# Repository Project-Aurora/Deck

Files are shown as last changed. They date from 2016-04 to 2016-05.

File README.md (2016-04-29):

# Deck
Breakout Boards for 64-Pin ARM MCUs, Keyswitches and IS31FL3732

# Components
+	MCU: The Microcontroller including one IS31FL3732 and a hot-pluggable Power-Connector (either Barrel Jack or MicroUSB)
+	Chain-Connector: Adds the Possibility to Connect two Devices over UART, an additional Master Pin enables automatic Crossover.
+	CherryMX-RGB: Breakout-Board for a single MX-Type Switch with either SMD or THT Backlighting. A Diode on the Back allows for "Ghostless" Operation. A 1-Wire EEPROM could enable Autodetection of different Switches/LEDs as well as Analog Input Devices.
+	LED-Driver: Breakout-Board for one IS31FL3732. These Boards are Chainable, the Device-Address can be freely assigned using external Connections. The Number of Boards can be enumerated using A/D-Conversion on chained Resistors.

Further Description in the Directories.

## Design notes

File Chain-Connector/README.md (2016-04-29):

Chain-Connector: Adds the Possibility to Connect two Devices over UART, an additional Master Pin enables automatic Crossover.

U1 Passes the [1-4]B Input to [1-4]Y when A/B is pulled high, otherwise it [1-4]A is passed through.
The Master Pin serves as A/B and is pulled high when the MCU has succsessfully established Connectivity to a USB-Host.
The "A" state of the Switch means IO1 serves as RX0 and IO2 as TX0.
The "B" state of the Switch means IO1 serves as TX0 and IO2 as RX0.
Because of this the UART-Connection can only be established when one of the two Devices has a USB-Connection, meaning the "RX" of Device1 is connected to Device2's "TX" and vice-versa.
D1 and D2 are needed because connecting the non "TX0" state of 1A and 4B to Ground would pull RX0 low. The EEPROM-Logic doesn't allow for undefined States, thus requireing some kind of connection.
A "Master-LED" (D3) lights up when the Master-Pin is pulled high.

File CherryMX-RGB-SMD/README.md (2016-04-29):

CherryMX-RGB-SMD: Breakout-Board for a single MX-Type Switch with SMD Backlighting. A Diode on the Back allows for "Ghostless" Operation. A 1-Wire EEPROM could enable Autodetection of different Switches/LEDs as well as Analog Input Devices.

The EEPROM is powered by the Row(3.3V) and Column(GND), because of this the Boards location in the Matrix can be determined despite the EEPROMs Address being fixed.

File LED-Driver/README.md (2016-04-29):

LED-Driver: Breakout-Board for one IS31FL3732. These Boards are Chainable, the Device-Address can be freely assigned using external Connections. The Number of Boards can be enumerated using A/D-Conversion on chained Resistors.

P3 offers the Pins necessary to set the Address-Pins on P4.
A table in the bottom right Corner shows an Overview of the Slave-ID(Columns) as well as the required Connections too ADDR1/s(Rows).

JP1 should be bridged on the last Device in Chain, shorting Feedback-IN to 3.3V.
R1 decreases the resulting current on each Device, allowing an AD-Converter Pin on the MCU to "guesstimate" the number of Resistors in Series and thus the Number of Slaves.

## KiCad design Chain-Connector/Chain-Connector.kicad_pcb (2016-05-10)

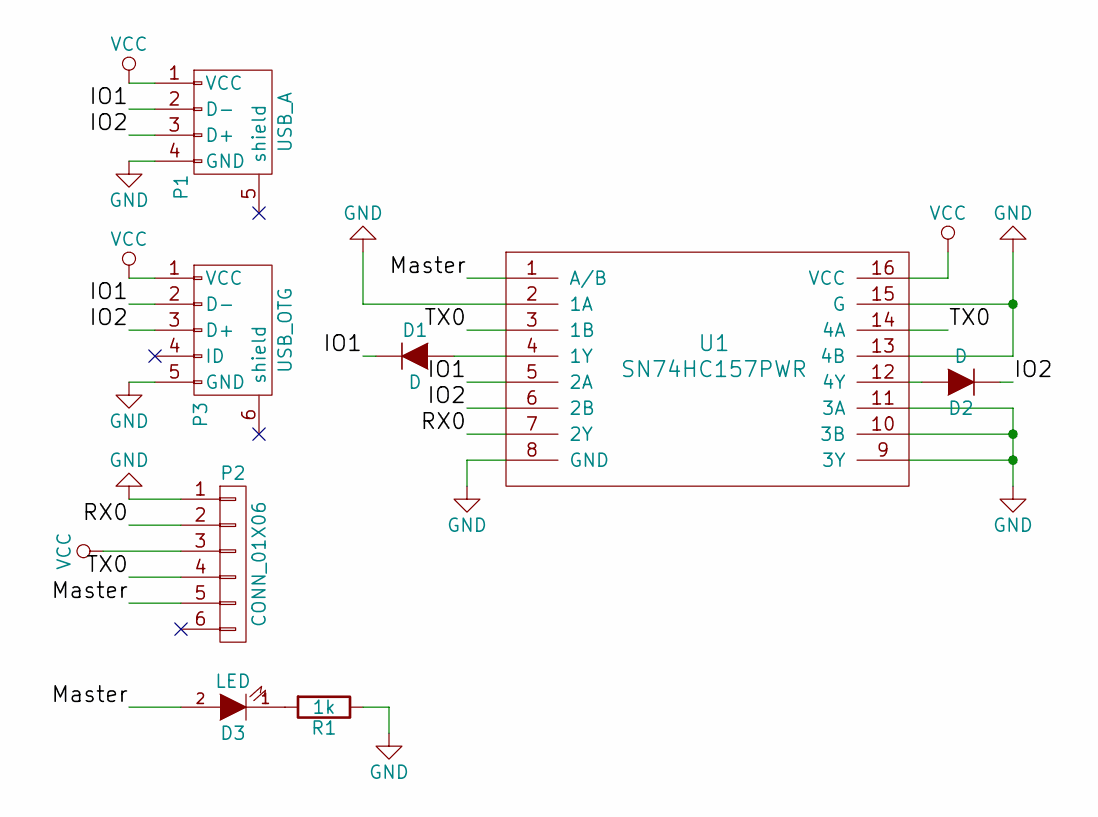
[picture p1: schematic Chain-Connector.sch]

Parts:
D1, D2: D; SOD-123
D3: LED; LED_0805
P1: USB_A
P2: CONN_01X06; Pin_Header_Straight_2x03
P3: USB_OTG; USB_Micro-B
R1: 1k; R_0603
U1: SN74HC157PWR; TSSOP-16_4.4x5mm_Pitch0.65mm

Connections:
/IO1: D1.1 (K), P1.2 (D-), P3.2 (D-), U1.5 (2A)
/IO2: D2.1 (K), P1.3 (D+), P3.3 (D+), U1.6 (2B)
/Master: D3.2 (A), P2.5, U1.1 (A/B)
/RX0: P2.2, U1.7 (2Y)
/TX0: P2.4, U1.3 (1B), U1.14 (4A)
GND: P1.4 (GND), P2.1, P3.5 (GND), R1.1, U1.2 (1A), U1.8 (GND), U1.9 (3Y), U1.10 (3B), U1.11 (3A), U1.13 (4B), U1.15 (G)
unnamed: D1.2 (A), U1.4 (1Y)
unnamed: D2.2 (A), U1.12 (4Y)
unnamed: D3.1 (K), R1.2
VCC: P1.1 (VCC), P2.3, P3.1 (VCC), U1.16 (VCC)

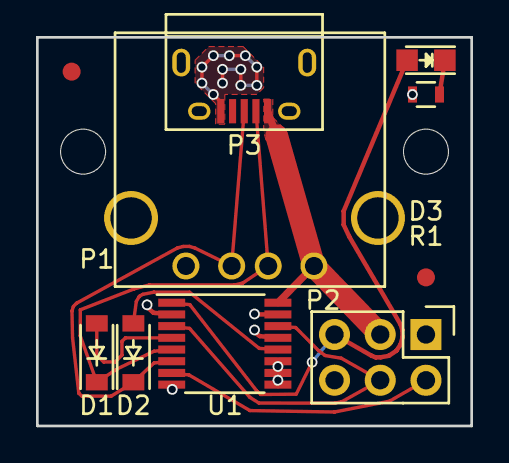
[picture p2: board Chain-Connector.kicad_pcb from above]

Board: 2 copper layers, 24.1 x 21.6 mm, 8 parts (0 on the bottom side), 10 nets.

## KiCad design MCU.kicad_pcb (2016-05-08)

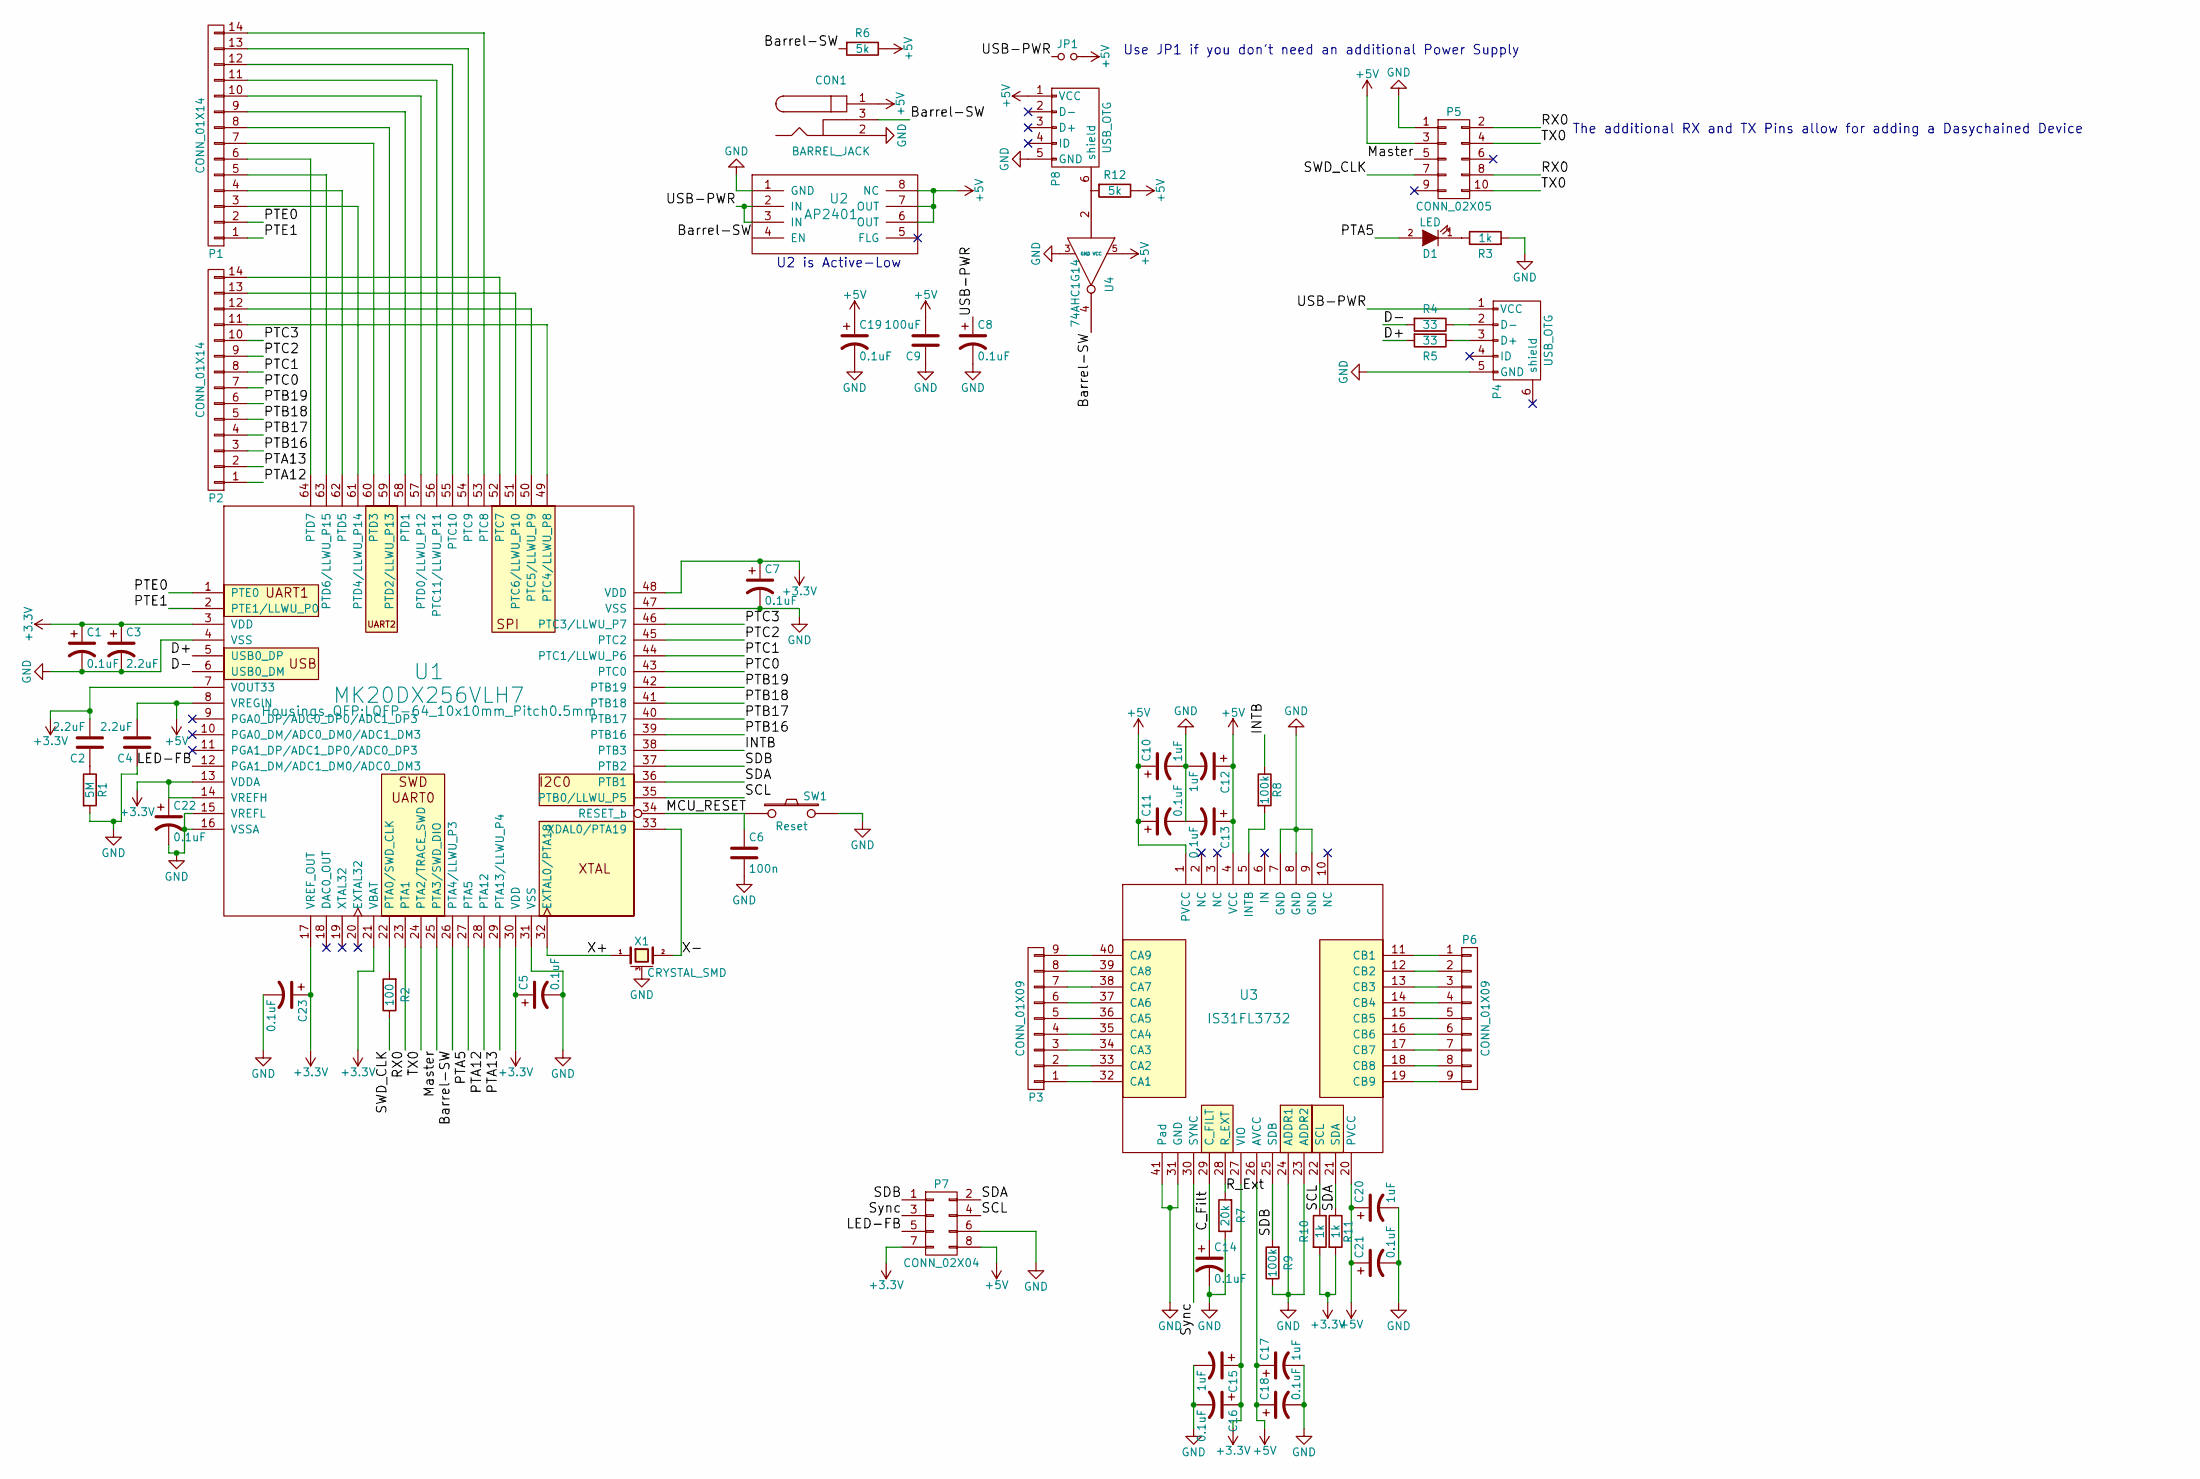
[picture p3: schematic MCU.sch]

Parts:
C1, C5, C7, C8, C11, C13, C14, C16, C18, C19, C21, C22, C23: 0.1uF; C_0603
C2, C3, C4: 2.2uF; C_0603
C6: 100n; C_0603
C9: 100uF; C_0805
C10, C12, C15, C17, C20: 1uF; C_0603
CON1: BARREL_JACK
D1: LED; LED_0805
JP1: Jumper_NO_Small; C_0805
P1, P2: CONN_01X14; Pin_Header_Straight_2x07
P3, P6: CONN_01X09; Pin_Header_Straight_1x09
P4, P8: USB_OTG; USB_Micro-B
P5: CONN_02X05; Pin_Header_Straight_2x05
P7: CONN_02X04; Pin_Header_Straight_2x04
R1: 5M; R_0805
R2: 100; R_0603
R3, R10, R11: 1k; R_0603
R4, R5: 33; R_0603
R6, R12: 5k; R_0603
R7: 20k; R_0603
R8, R9: 100k; R_0603
SW1: Reset; SW_Tactile_SPST_Angled
U1: MK20DX256VLH7; LQFP-64_10x10mm_Pitch0.5mm
U2: AP2401; SO-8
U3: IS31FL3732; UQFN-40-1EP_5x5mm_Pitch0.4mm
U4: 74AHC1G14; SOT-353
X1: CRYSTAL_SMD; crystal_FA238-TSX3225

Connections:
+3V3: C1.1, C2.2, C3.1, C5.1, C7.1, C15.1, C16.1, C22.1, C23.1, P7.7, R10.2, R11.2, U1.3 (VDD), U1.7 (VOUT33), U1.13 (VDDA), U1.14 (VREFH), U1.17 (VREF_OUT), U1.21 (VBAT), U1.30 (VDD), U1.48 (VDD), U3.27 (VIO)
+5V: C4.2, C9.2, C10.1, C11.1, C12.1, C13.1, C17.1, C18.1, C19.1, C20.1, C21.1, CON1.1, JP1.2, P5.3, P7.8, P8.1 (VCC), R6.1, R12.1, U1.8 (VREGIN), U2.6 (OUT), U2.7 (OUT), U2.8 (NC), U3.1 (PVCC), U3.4 (VCC), U3.20 (PVCC), U3.26 (AVCC), U4.5 (VCC)
/Barrel-SW: CON1.3, R6.2, U1.26 (PTA4/LLWU_P3), U2.4 (EN), U4.4
/C_Filt: C14.1, U3.29 (C_FILT)
/D+: R5.2, U1.5 (USB0_DP)
/D-: R4.2, U1.6 (USB0_DM)
/INTB: R8.1, U1.38 (PTB3)
/LED-FB: P7.5, U1.12 (PGA1_DM/ADC1_DM0/ADC0_DM3)
/MCU_RESET: C6.1, SW1.1, U1.34 (RESET_b)
/Master: P5.5, U1.25 (PTA3/SWD_DIO)
/PTA5: D1.2 (A), U1.27 (PTA5)
/PTA12: P2.1, U1.28 (PTA12)
/PTA13: P2.2, U1.29 (PTA13/LLWU_P4)
/PTB16: P2.3, U1.39 (PTB16)
/PTB17: P2.4, U1.40 (PTB17)
/PTB18: P2.5, U1.41 (PTB18)
/PTB19: P2.6, U1.42 (PTB19)
/PTC0: P2.7, U1.43 (PTC0)
/PTC1: P2.8, U1.44 (PTC1/LLWU_P6)
/PTC2: P2.9, U1.45 (PTC2)
/PTC3: P2.10, U1.46 (PTC3/LLWU_P7)
/PTE0: P1.2, U1.1 (PTE0)
/PTE1: P1.1, U1.2 (PTE1/LLWU_P0)
/RX0: P5.2, P5.8, U1.23 (PTA1)
/R_Ext: R7.2, U3.28 (R_EXT)
/SCL: P7.4, R10.1, U1.35 (PTB0/LLWU_P5), U3.22 (SCL)
/SDA: P7.2, R11.1, U1.36 (PTB1), U3.21 (SDA)
/SDB: P7.1, R9.2, U1.37 (PTB2), U3.25 (SDB)
/SWD_CLK: P5.7, R2.1
/Sync: P7.3, U3.30 (SYNC)
/TX0: P5.4, P5.10, U1.24 (PTA2/TRACE_SWD)
/USB-PWR: C8.1, JP1.1, P4.1 (VCC), U2.2 (IN), U2.3 (IN)
/X+: U1.32 (EXTAL0/PTA18), X1.1
/X-: U1.33 (XDAL0/PTA19), X1.2
GND: C1.2, C3.2, C4.1, C5.2, C6.2, C7.2, C8.2, C9.1, C10.2, C11.2, C12.2, C13.2, C14.2, C15.2, C16.2, C17.2, C18.2, C19.2, C20.2, C21.2, C22.2, C23.2, CON1.2, P4.5 (GND), P5.1, P7.6, P8.5 (GND), R1.2, R3.2, R7.1, R9.1, SW1.2, U1.4 (VSS), U1.15 (VREFL), U1.16 (VSSA), U1.31 (VSS), U1.47 (VSS), U2.1 (GND), U3.7 (GND), U3.8 (GND), U3.9 (GND), U3.23 (ADDR2), U3.24 (ADDR1), U3.31 (GND), U3.41 (Pad), U4.3 (GND), X1.3 (case)
unnamed: C2.1, R1.1
unnamed: D1.1 (K), R3.1
unnamed: P1.3, U1.61 (PTD4/LLWU_P14)
unnamed: P1.4, U1.62 (PTD5)
unnamed: P1.5, U1.63 (PTD6/LLWU_P15)
unnamed: P1.6, U1.64 (PTD7)
unnamed: P1.7, U1.60 (PTD3)
unnamed: P1.8, U1.59 (PTD2/LLWU_P13)
unnamed: P1.9, U1.58 (PTD1)
unnamed: P1.10, U1.57 (PTD0/LLWU_P12)
unnamed: P1.11, U1.56 (PTC11/LLWU_P11)
unnamed: P1.12, U1.55 (PTC10)
unnamed: P1.13, U1.54 (PTC9)
unnamed: P1.14, U1.53 (PTC8)
unnamed: P2.11, U1.49 (PTC4/LLWU_P8)
unnamed: P2.12, U1.50 (PTC5/LLWU_P9)
unnamed: P2.13, U1.51 (PTC6/LLWU_P10)
unnamed: P2.14, U1.52 (PTC7)
unnamed: P3.1, U3.32 (CA1)
unnamed: P3.2, U3.33 (CA2)
unnamed: P3.3, U3.34 (CA3)
unnamed: P3.4, U3.35 (CA4)
unnamed: P3.5, U3.36 (CA5)
unnamed: P3.6, U3.37 (CA6)
unnamed: P3.7, U3.38 (CA7)
unnamed: P3.8, U3.39 (CA8)
unnamed: P3.9, U3.40 (CA9)
unnamed: P4.2 (D-), R4.1
unnamed: P4.3 (D+), R5.1
unnamed: P6.1, U3.11 (CB1)
unnamed: P6.2, U3.12 (CB2)
unnamed: P6.3, U3.13 (CB3)
unnamed: P6.4, U3.14 (CB4)
unnamed: P6.5, U3.15 (CB5)
unnamed: P6.6, U3.16 (CB6)
unnamed: P6.7, U3.17 (CB7)
unnamed: P6.8, U3.18 (CB8)
unnamed: P6.9, U3.19 (CB9)
unnamed: P8.6 (shield), R12.2, U4.2
unnamed: R2.2, U1.22 (PTA0/SWD_CLK)
unnamed: R8.2, U3.5 (INTB)

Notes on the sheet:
Use JP1 if you don't need an additional Power Supply
U2 is Active-Low
The additional RX and TX Pins allow for adding a Dasychained Device

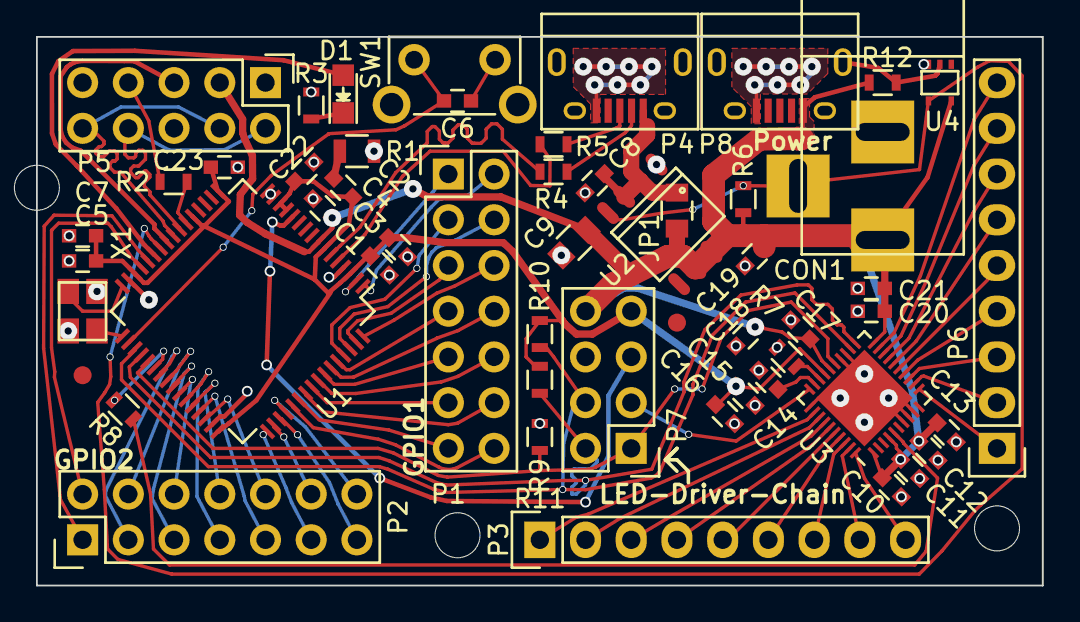
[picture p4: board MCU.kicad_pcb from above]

Board: 2 copper layers, 55.9 x 30.5 mm, 52 parts (0 on the bottom side), 76 nets.

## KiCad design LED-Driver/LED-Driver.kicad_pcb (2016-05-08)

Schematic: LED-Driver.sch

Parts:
C1, C2, C5, C8, C9: 1uF; C_0603
C3, C4, C6, C7, C10, C11: 0.1uF; C_0603
JP1: Jumper_NO_Small; Pin_Header_Straight_1x02
P1, P2: CONN_02X04; Pin_Header_Straight_2x04
P3: CONN_01X05; Pin_Header_Straight_1x05
P4: CONN_01X02; Pin_Header_Straight_1x02
P5, P6: CONN_01X09; Pin_Header_Straight_1x09
R1: 1234; R_0603
R2: 20k; R_0603
U1: IS31FL3732; UQFN-40-1EP_5x5mm_Pitch0.4mm

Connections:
+3V3: C8.1, C10.1, JP1.1, P1.7, P2.7, U1.27 (VIO)
+5V: C1.1, C2.1, C3.1, C4.1, C5.1, C7.1, C9.1, C11.1, P1.8, P2.8, P3.2, P3.3, U1.1 (PVCC), U1.4 (VCC), U1.20 (PVCC), U1.26 (AVCC)
/ADDR1: P4.1, U1.24 (ADDR1)
/ADDR2: P4.2, U1.23 (ADDR2)
/C_Filt: C6.1, U1.29 (C_FILT)
/Feedback-IN: JP1.2, P1.5, R1.1
/Feedback-OUT: P2.5, R1.2
/R_Ext: R2.2, U1.28 (R_EXT)
/SCL: P1.4, P2.4, P3.5, U1.22 (SCL)
/SDA: P1.2, P2.2, P3.4, U1.21 (SDA)
/SDB: P1.1, P2.1, U1.25 (SDB)
/Sync: P1.3, P2.3, U1.30 (SYNC)
GND: C1.2, C2.2, C3.2, C4.2, C5.2, C6.2, C7.2, C8.2, C9.2, C10.2, C11.2, P1.6, P2.6, P3.1, R2.1, U1.7 (GND), U1.8 (GND), U1.9 (GND), U1.31 (GND), U1.41 (Pad)
unnamed: P5.1, U1.32 (CA1)
unnamed: P5.2, U1.33 (CA2)
unnamed: P5.3, U1.34 (CA3)
unnamed: P5.4, U1.35 (CA4)
unnamed: P5.5, U1.36 (CA5)
unnamed: P5.6, U1.37 (CA6)
unnamed: P5.7, U1.38 (CA7)
unnamed: P5.8, U1.39 (CA8)
unnamed: P5.9, U1.40 (CA9)
unnamed: P6.1, U1.11 (CB1)
unnamed: P6.2, U1.12 (CB2)
unnamed: P6.3, U1.13 (CB3)
unnamed: P6.4, U1.14 (CB4)
unnamed: P6.5, U1.15 (CB5)
unnamed: P6.6, U1.16 (CB6)
unnamed: P6.7, U1.17 (CB7)
unnamed: P6.8, U1.18 (CB8)
unnamed: P6.9, U1.19 (CB9)

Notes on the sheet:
OUT

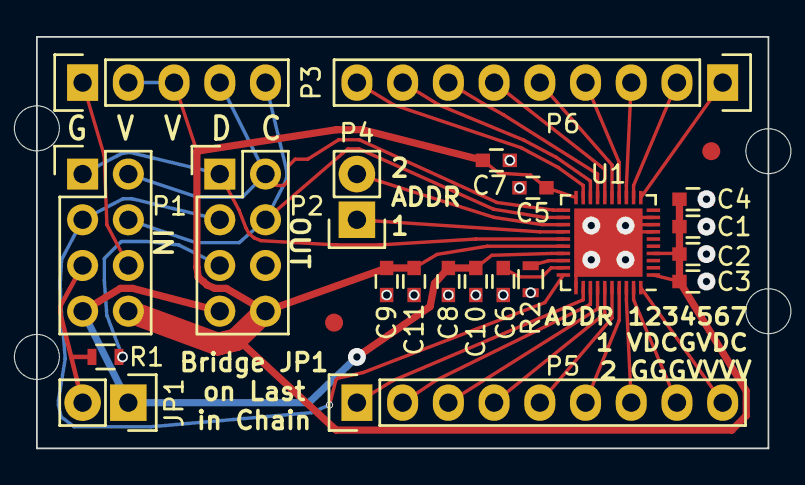
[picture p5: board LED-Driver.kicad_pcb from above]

Board: 2 copper layers, 40.6 x 22.9 mm, 21 parts (0 on the bottom side), 31 nets.

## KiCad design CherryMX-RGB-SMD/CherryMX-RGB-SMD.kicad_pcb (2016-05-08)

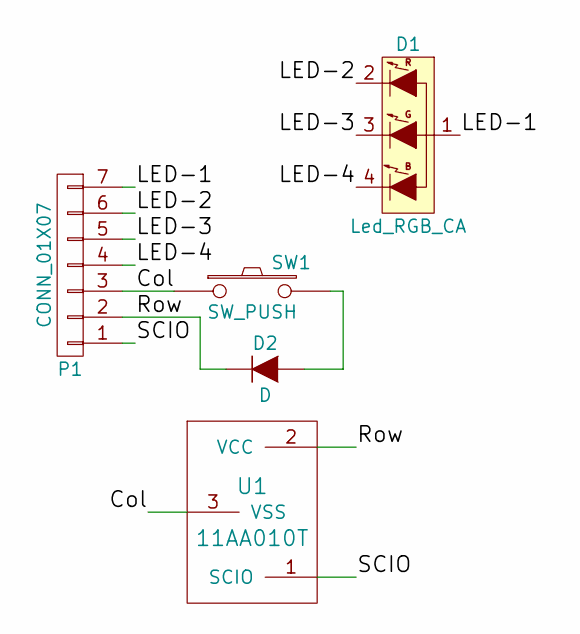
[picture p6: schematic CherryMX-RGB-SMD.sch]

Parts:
D1: Led_RGB_CA; SMD_0606_4PAD
D2: D; SOD-123
P1: CONN_01X07; Pin_Header_Straight_1x07
SW1: SW_PUSH; MX1A
U1: 11AA010T; SOT-23

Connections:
/Col: P1.3, SW1.1, U1.3 (VSS)
/LED-1: D1.1, P1.7
/LED-2: D1.2 (R), P1.6
/LED-3: D1.3 (G), P1.5
/LED-4: D1.4 (B), P1.4
/Row: D2.1 (K), P1.2, U1.2 (VCC)
/SCIO: P1.1, U1.1 (SCIO)
unnamed: D2.2 (A), SW1.2

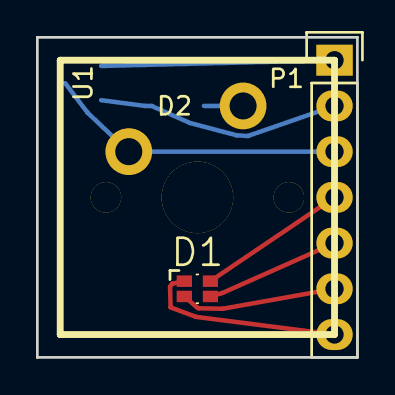
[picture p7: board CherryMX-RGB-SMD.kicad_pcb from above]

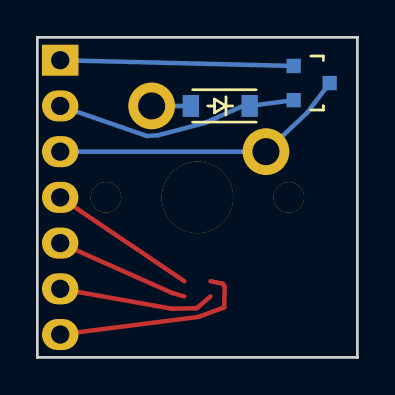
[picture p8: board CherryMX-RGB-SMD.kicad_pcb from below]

Board: 2 copper layers, 17.8 x 17.8 mm, 5 parts (2 on the bottom side), 8 nets.

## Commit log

2016-04-29 Added Readmes to the Subdirectorys
    Fixed placement of some Silkscreen-Stuff on the LED-Driver as well.
    [LED-Driver.kicad_pcb]
2016-05-01 Added Analog-Digital Conversion Capability
    [MCU.kicad_pcb, MCU.sch]
2016-05-02 Made PCB more Manufacturer-friendly
    [MCU.kicad_pcb]
2016-05-04 Switched to 2.5mm Mounting Holes
    [Chain-Connector.kicad_pcb, LED-Driver.kicad_pcb, MCU.kicad_pcb]
2016-05-04 More appropriate Placement of Mounting-Holes
    [MCU.kicad_pcb]
2016-05-05 Added the Option to use an SMD-LED on Backside
    When using a single-color THT LED on the Front
    [CherryMX-RGB-THT.kicad_pcb, CherryMX-RGB-THT.sch]
2016-05-08 Minor cleanups
    [CherryMX-RGB-SMD.kicad_pcb, LED-Driver.kicad_pcb, MCU.kicad_pcb]
2016-05-08 Adjusted a Trace on the Chain-Connector as well
    [Chain-Connector.kicad_pcb]
2016-05-10 Added the Option to use a Micro-USB Connector
    And also revamped the Routing to be less of a Mess
    [Chain-Connector.kicad_pcb, Chain-Connector.sch]
